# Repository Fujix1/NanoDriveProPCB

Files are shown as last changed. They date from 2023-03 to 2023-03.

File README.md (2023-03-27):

# NanoDriveProPCB
This is a PCB design repository for NanoDrive PRO

<br />この 作品 は <a rel="license" href="http://creativecommons.org/licenses/by-nc-sa/4.0/">クリエイティブ・コモンズ 表示 - 非営利 - 継承 4.0 国際 ライセンス</a>の下に提供されています。

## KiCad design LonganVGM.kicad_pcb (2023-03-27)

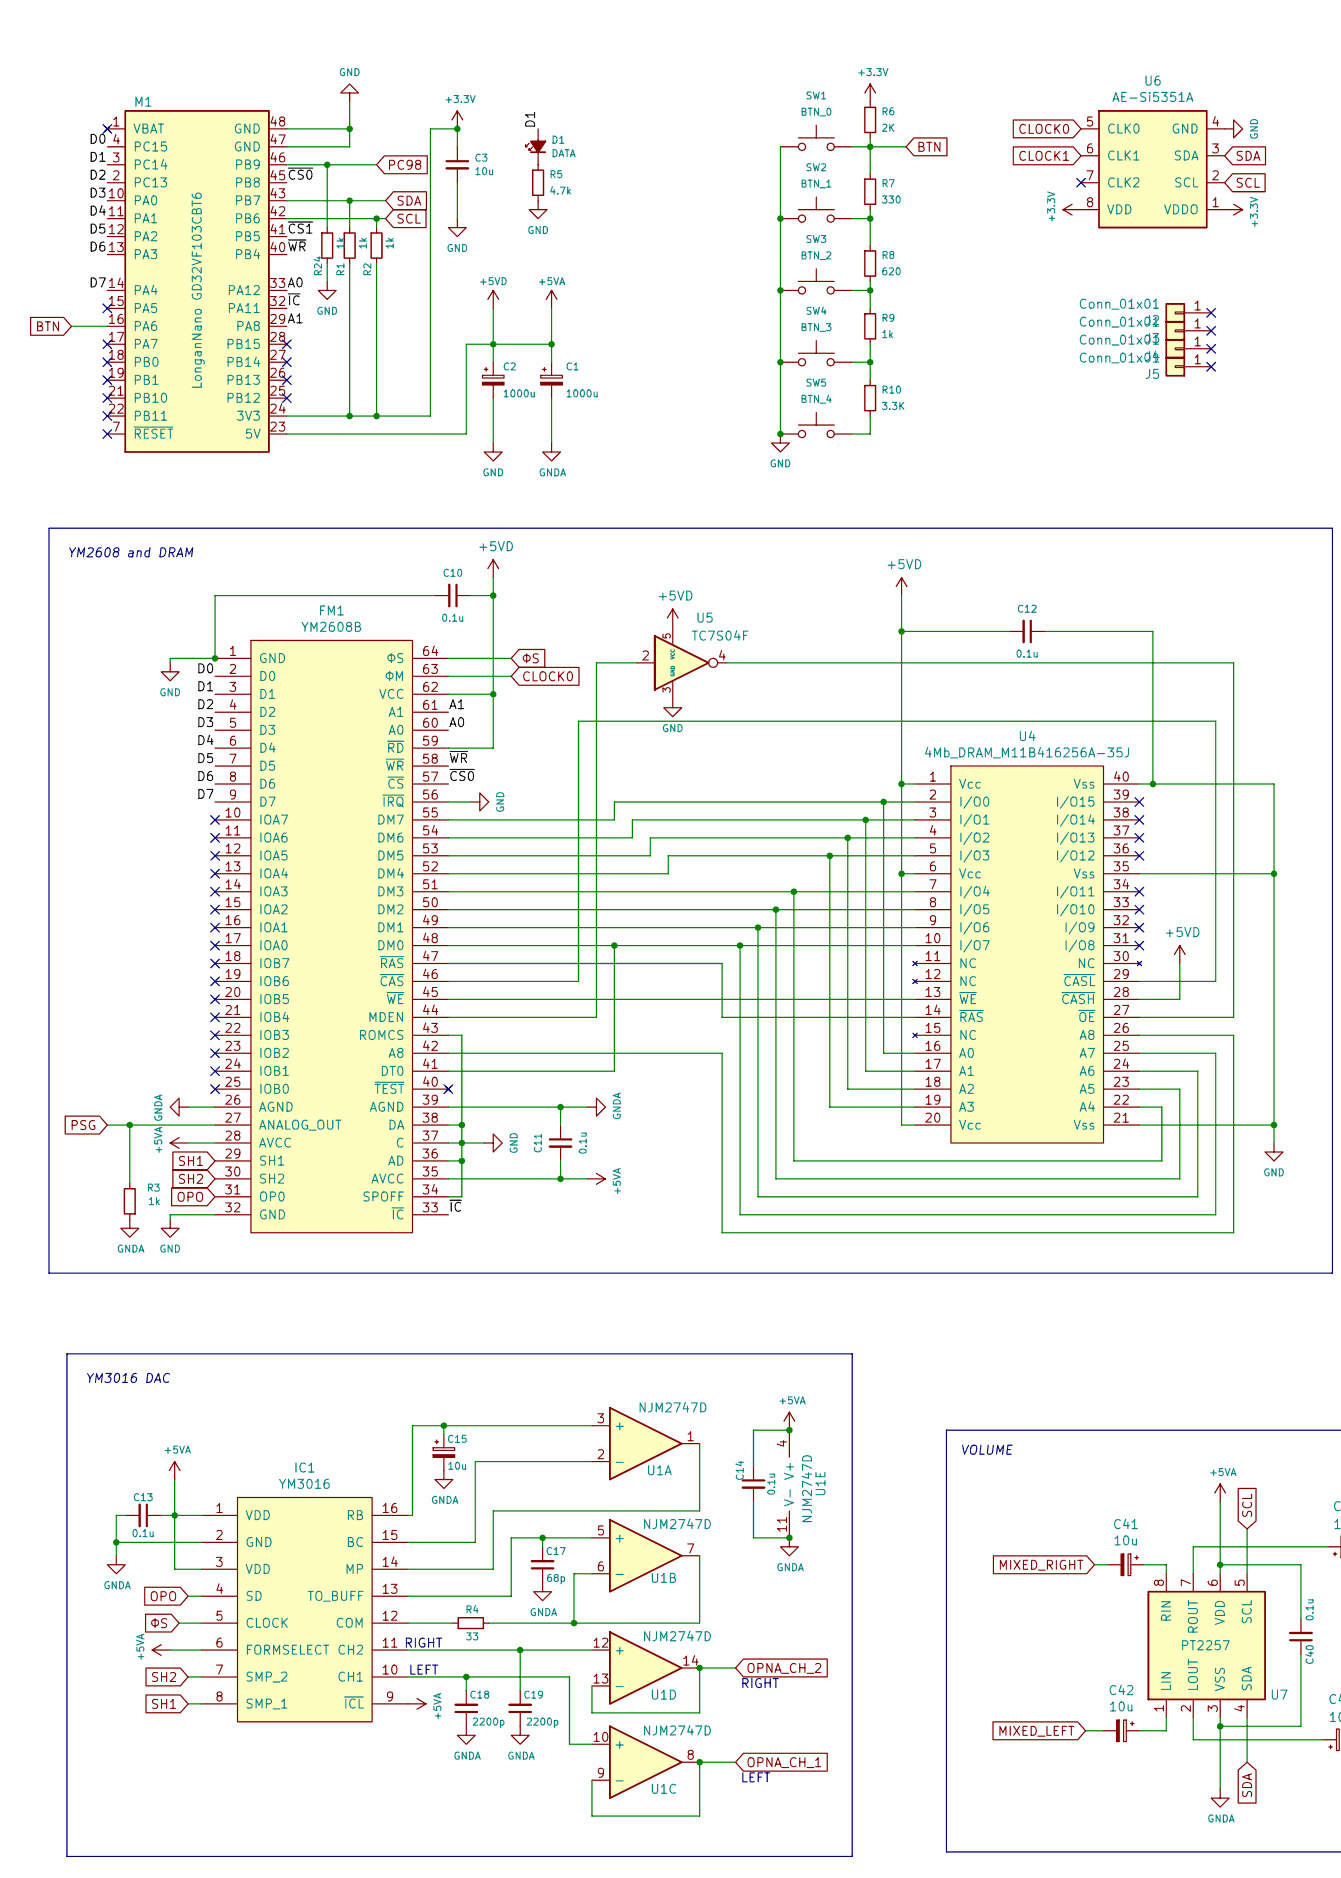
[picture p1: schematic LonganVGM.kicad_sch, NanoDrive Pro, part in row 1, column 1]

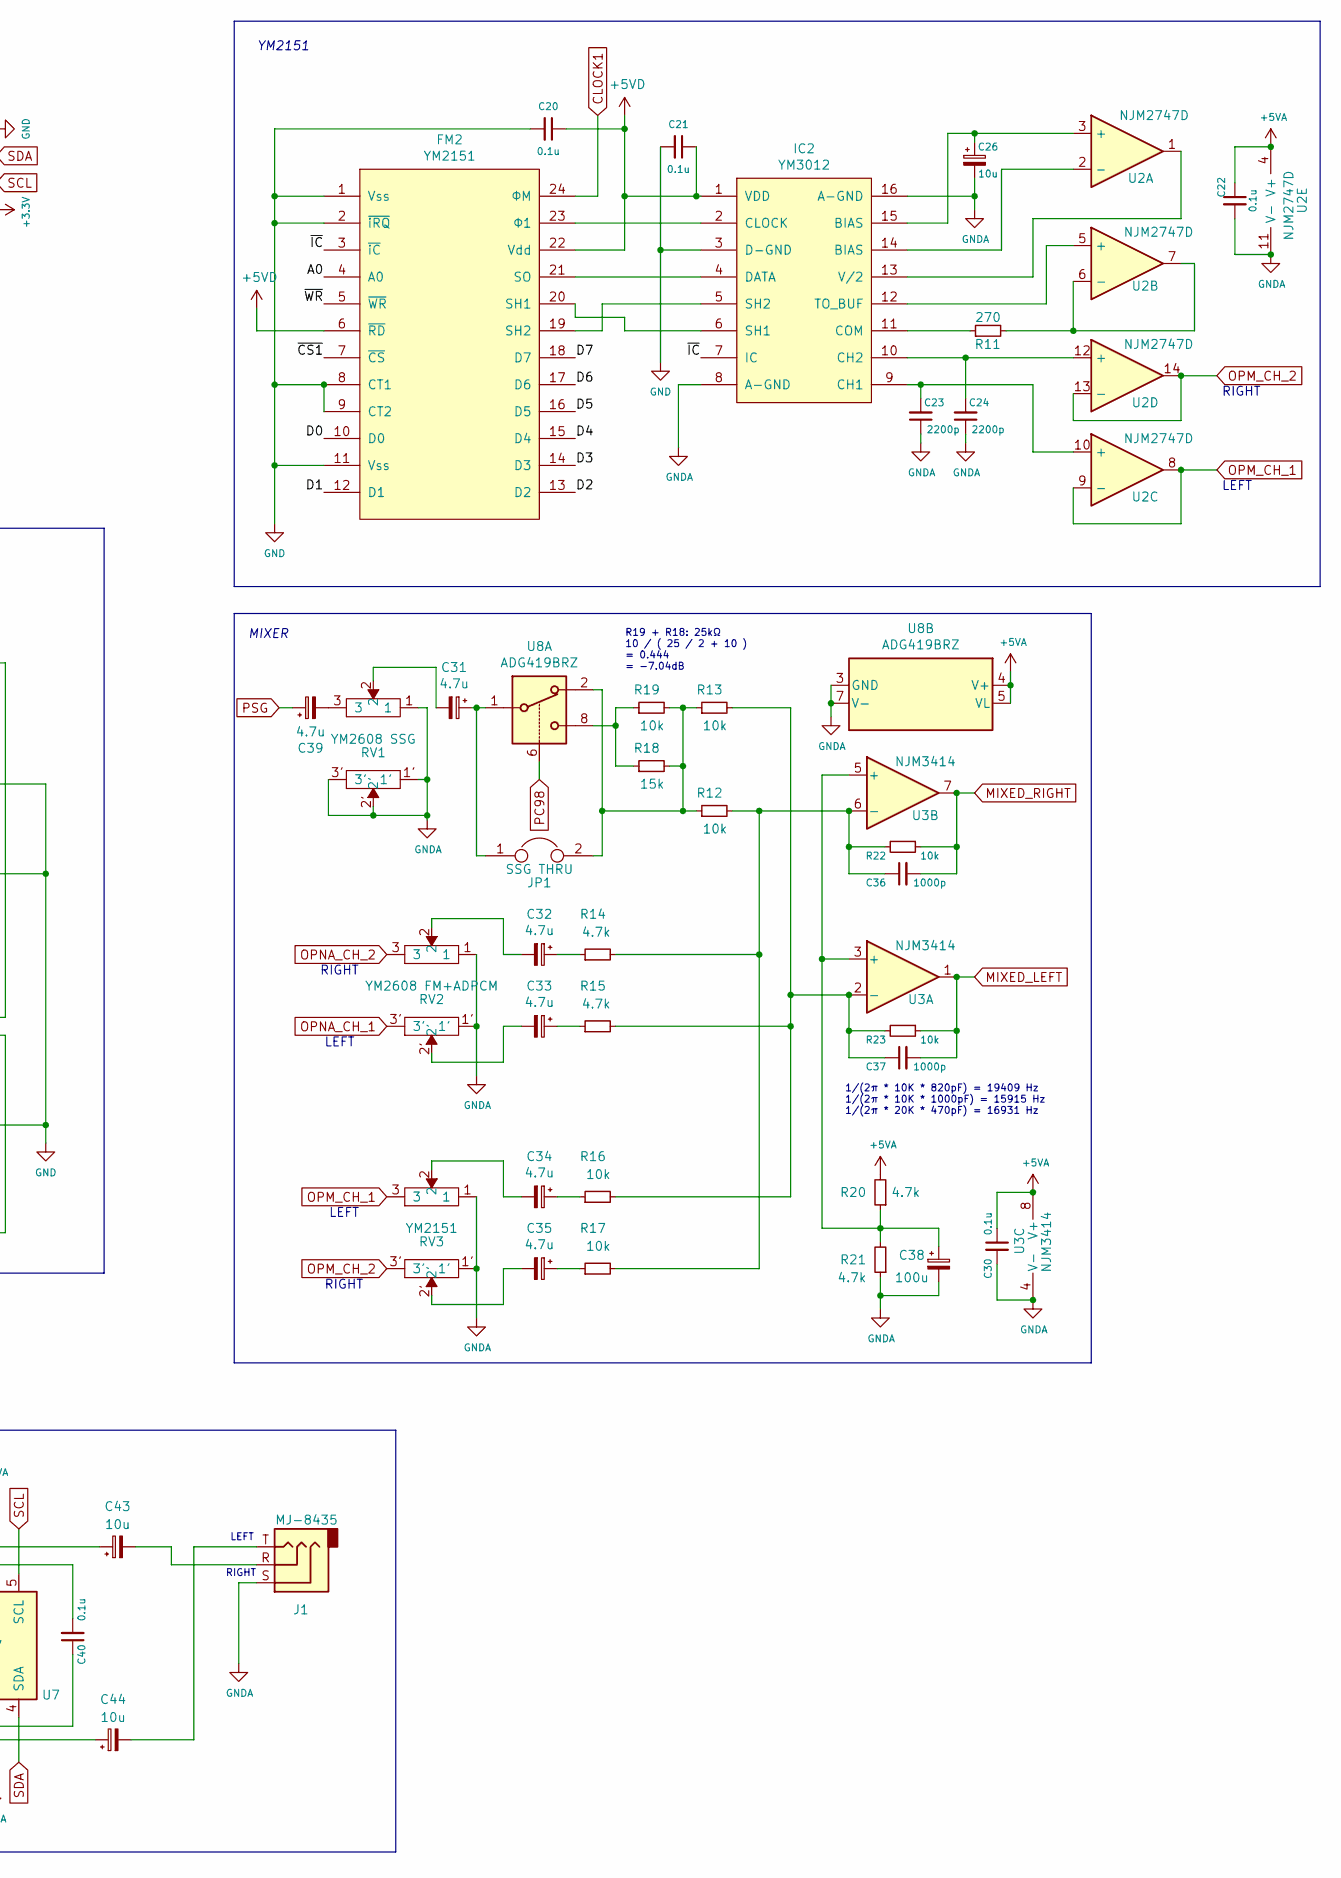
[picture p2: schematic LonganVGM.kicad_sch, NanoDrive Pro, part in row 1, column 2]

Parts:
C1, C2: 1000u; CP_Radial_D8.0mm_P3.50mm
C3, C15, C26, C41, C42, C43, C44: 10u; CP_Radial_D5.0mm_P2.00mm
C10, C11, C12, C13, C14, C20, C21, C22, C30, C40: 0.1u; C_Disc_D4.3mm_W1.9mm_P5.00mm
C17: 68p; C_Disc_D4.3mm_W1.9mm_P5.00mm
C18, C19, C23, C24: 2200p; C_Disc_D4.3mm_W1.9mm_P5.00mm
C31, C32, C33, C34, C35, C39: 4.7u; CP_Radial_D5.0mm_P2.00mm
C36, C37: 1000p; C_Disc_D4.3mm_W1.9mm_P5.00mm
C38: 100u; CP_Radial_D6.3mm_P2.50mm
D1: DATA; LED_Rectangular_W5.0mm_H2.0mm
FM1: YM2608B; SDIP-64
FM2: YM2151; DIP-24_W15.24mm_Socket
IC1: YM3016; DIP-16_W7.62mm_Socket
IC2: YM3012; DIP-16_W7.62mm_Socket
J1: MJ-8435; MJ8435
J2, J3, J4, J5: Conn_01x01; hole
JP1: SSG THRU; PinHeader_1x02_P2.54mm_Vertical
M1: LonganNano GD32VF103CBT6; LonganNano
R1, R2, R3, R9, R24: 1k; R_Axial_DIN0207_L6.3mm_D2.5mm_P7.62mm_Horizontal
R4: 33; R_Axial_DIN0207_L6.3mm_D2.5mm_P7.62mm_Horizontal
R5, R14, R15, R20, R21: 4.7k; R_Axial_DIN0207_L6.3mm_D2.5mm_P7.62mm_Horizontal
R6: 2K; R_Axial_DIN0207_L6.3mm_D2.5mm_P7.62mm_Horizontal
R7: 330; R_Axial_DIN0207_L6.3mm_D2.5mm_P7.62mm_Horizontal
R8: 620; R_Axial_DIN0207_L6.3mm_D2.5mm_P7.62mm_Horizontal
R10: 3.3K; R_Axial_DIN0207_L6.3mm_D2.5mm_P7.62mm_Horizontal
R11: 270; R_Axial_DIN0207_L6.3mm_D2.5mm_P7.62mm_Horizontal
R12, R13, R16, R17, R19, R22, R23: 10k; R_Axial_DIN0207_L6.3mm_D2.5mm_P7.62mm_Horizontal
R18: 15k; R_Axial_DIN0207_L6.3mm_D2.5mm_P7.62mm_Horizontal
RV1: YM2608 SSG; RK12L
RV2: YM2608 FM+ADPCM; RK12L
RV3: YM2151; RK12L
SW1: BTN_0; SW_PUSH_6mm_H4.3mm
SW2: BTN_1; SW_PUSH_6mm_H4.3mm
SW3: BTN_2; SW_PUSH_6mm_H4.3mm
SW4: BTN_3; SW_PUSH_6mm_H4.3mm
SW5: BTN_4; SW_PUSH_6mm_H4.3mm
U1, U2: NJM2747D; DIP-14_W7.62mm_Socket
U3: NJM3414; DIP-8_W7.62mm_Socket
U4: 4Mb_DRAM_M11B416256A-35J; SOP-40
U5: TC7S04F; SOT-23-5_HandSoldering
U6: AE-Si5351A; DIP-8_W7.62mm_Socket
U7: PT2257; DIP-8_W7.62mm_Socket
U8: ADG419BRZ; SO-8_3.9x4.9mm_P1.27mm_handsolder

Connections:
+3V3: C3.1, M1.24 (3V3), R1.2, R2.2, R6.1, U6.1 (VDDO), U6.8 (VDD)
+5VA: C1.1, C2.1, C10.1, C11.2, C12.2, C13.1, C14.1, C20.1, C21.1, C22.1, C30.1, C40.2, FM1.28 (AVCC), FM1.35 (AVCC), FM1.59 (~RD), FM1.62 (VCC), FM2.6 (~RD), FM2.22 (Vdd), IC1.1 (VDD), IC1.3 (VDD), IC1.6 (FORMSELECT), IC1.9 (~ICL), IC2.1 (VDD), M1.23 (5V), R20.2, U1.4 (V+), U2.4 (V+), U3.8 (V+), U4.1 (Vcc), U4.6 (Vcc), U4.20 (Vcc), U4.28 (~CASH), U5.5 (VCC), U7.6 (VDD), U8.4 (V+), U8.5 (VL)
/A0: FM1.60 (A0), FM2.4 (A0), M1.33 (PA12)
/A1: FM1.61 (A1), M1.29 (PA8)
/D0: FM1.2 (D0), FM2.10 (D0), M1.4 (PC15)
/D1: D1.2 (A), FM1.3 (D1), FM2.12 (D1), M1.3 (PC14)
/D2: FM1.4 (D2), FM2.13 (D2), M1.2 (PC13)
/D3: FM1.5 (D3), FM2.14 (D3), M1.10 (PA0)
/D4: FM1.6 (D4), FM2.15 (D4), M1.11 (PA1)
/D5: FM1.7 (D5), FM2.16 (D5), M1.12 (PA2)
/D6: FM1.8 (D6), FM2.17 (D6), M1.13 (PA3)
/D7: FM1.9 (D7), FM2.18 (D7), M1.14 (PA4)
/~CS0: FM1.57 (~CS), M1.45 (PB8)
/~CS1: FM2.7 (~CS), M1.41 (PB5)
/~IC: FM1.33 (~IC), FM2.3 (~iC), IC2.7 (IC), M1.32 (PA11)
/~WR: FM1.58 (~WR), FM2.5 (~WR), M1.40 (PB4)
BTN: M1.16 (PA6), R6.2, R7.1, SW1.2
CLOCK0: FM1.63 (ΦM), U6.5 (CLK0)
CLOCK1: FM2.24 (ΦM), U6.6 (CLK1)
MIXED_LEFT: C37.2, C42.2, R23.1, U3.1
MIXED_RIGHT: C36.2, C41.2, R22.1, U3.7
unnamed: C15.1, IC1.16 (RB), U1.3 (+)
unnamed: C17.2, IC1.13 (TO_BUFF), U1.5 (+)
unnamed: C18.2, IC1.10 (CH1), U1.10 (+)
unnamed: C19.2, IC1.11 (CH2), U1.12 (+)
unnamed: C23.2, IC2.9 (CH1), U2.10 (+)
unnamed: C24.2, IC2.10 (CH2), U2.12 (+)
unnamed: C26.1, IC2.15 (BIAS), U2.3 (+)
unnamed: C31.1, JP1.1, U8.1
unnamed: C31.2, RV1.2
unnamed: C32.1, R14.1
unnamed: C32.2, RV2.2
unnamed: C33.1, R15.1
unnamed: C33.2, RV2.2'
unnamed: C34.1, R16.1
unnamed: C34.2, RV3.2
unnamed: C35.1, R17.1
unnamed: C35.2, RV3.2'
unnamed: C36.1, R12.2, R14.2, R17.2, R22.2, U3.6 (-)
unnamed: C37.1, R13.2, R15.2, R16.2, R23.2, U3.2 (-)
unnamed: C38.1, R20.1, R21.2, U3.3 (+), U3.5 (+)
unnamed: C39.2, RV1.3
unnamed: C41.1, U7.8 (RIN)
unnamed: C42.1, U7.1 (LIN)
unnamed: C43.1, U7.7 (ROUT)
unnamed: C43.2, J1.R
unnamed: C44.1, U7.2 (LOUT)
unnamed: C44.2, J1.T
unnamed: D1.1 (K), R5.1
unnamed: FM1.41 (DT0), FM1.48 (DM0), U4.10 (I/O7), U4.25 (A7)
unnamed: FM1.42 (A8), U4.26 (A8)
unnamed: FM1.44 (MDEN), U5.2
unnamed: FM1.45 (~WE), U4.13 (~WE)
unnamed: FM1.46 (~CAS), U4.29 (~CASL)
unnamed: FM1.47 (~RAS), U4.14 (~RAS)
unnamed: FM1.49 (DM1), U4.9 (I/O6), U4.24 (A6)
unnamed: FM1.50 (DM2), U4.8 (I/O5), U4.23 (A5)
unnamed: FM1.51 (DM3), U4.7 (I/O4), U4.22 (A4)
unnamed: FM1.52 (DM4), U4.5 (I/O3), U4.19 (A3)
unnamed: FM1.53 (DM5), U4.4 (I/O2), U4.18 (A2)
unnamed: FM1.54 (DM6), U4.3 (I/O1), U4.17 (A1)
unnamed: FM1.55 (DM7), U4.2 (I/O0), U4.16 (A0)
unnamed: FM2.19 (SH2), IC2.5 (SH2)
unnamed: FM2.20 (SH1), IC2.6 (SH1)
unnamed: FM2.21 (SO), IC2.4 (DATA)
unnamed: FM2.23 (Φ1), IC2.2 (CLOCK)
unnamed: IC1.12 (COM), R4.1
unnamed: IC1.14 (MP), U1.1
unnamed: IC1.15 (BC), U1.2 (-)
unnamed: IC2.11 (COM), R11.1
unnamed: IC2.12 (TO_BUF), U2.5 (+)
unnamed: IC2.13 (V/2), U2.1
unnamed: IC2.14 (BIAS), U2.2 (-)
unnamed: JP1.2, R12.1, R13.1, R18.2, R19.2, U8.2
unnamed: R4.2, U1.6 (-), U1.7
unnamed: R7.2, R8.1, SW2.2
unnamed: R8.2, R9.1, SW3.2
unnamed: R9.2, R10.1, SW4.2
unnamed: R10.2, SW5.2
unnamed: R11.2, U2.6 (-), U2.7
unnamed: R18.1, R19.1, U8.8
unnamed: U4.27 (~OE), U5.4
OPM_CH_1: RV3.3, U2.8, U2.9 (-)
OPM_CH_2: RV3.3', U2.13 (-), U2.14
OPNA_CH_1: RV2.3', U1.8, U1.9 (-)
OPNA_CH_2: RV2.3, U1.13 (-), U1.14
OPO: FM1.31 (OP0), IC1.4 (SD)
PC98: M1.46 (PB9), R24.1, U8.6
PSG: C39.1, FM1.27 (ANALOG_OUT), R3.2
SCL: M1.42 (PB6), R2.1, U6.2 (SCL), U7.5 (SCL)
SDA: M1.43 (PB7), R1.1, U6.3 (SDA), U7.4 (SDA)
SH1: FM1.29 (SH1), IC1.8 (SMP_1)
SH2: FM1.30 (SH2), IC1.7 (SMP_2)
ΦS: FM1.64 (ΦS), IC1.5 (CLOCK)

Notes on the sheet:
RIGHT
LEFT
R19 + R18: 25kΩ 10 / ( 25 / 2 + 10 ) = 0.444 = -7.04dB
1/(2π * 10K * 820pF) = 19409 Hz 1/(2π * 10K * 1000pF) = 15915 Hz 1/(2π * 20K * 470pF) = 16931 Hz
YM2608 and DRAM
RIGHT
YM2151
YM3016 DAC
MIXER
VOLUME

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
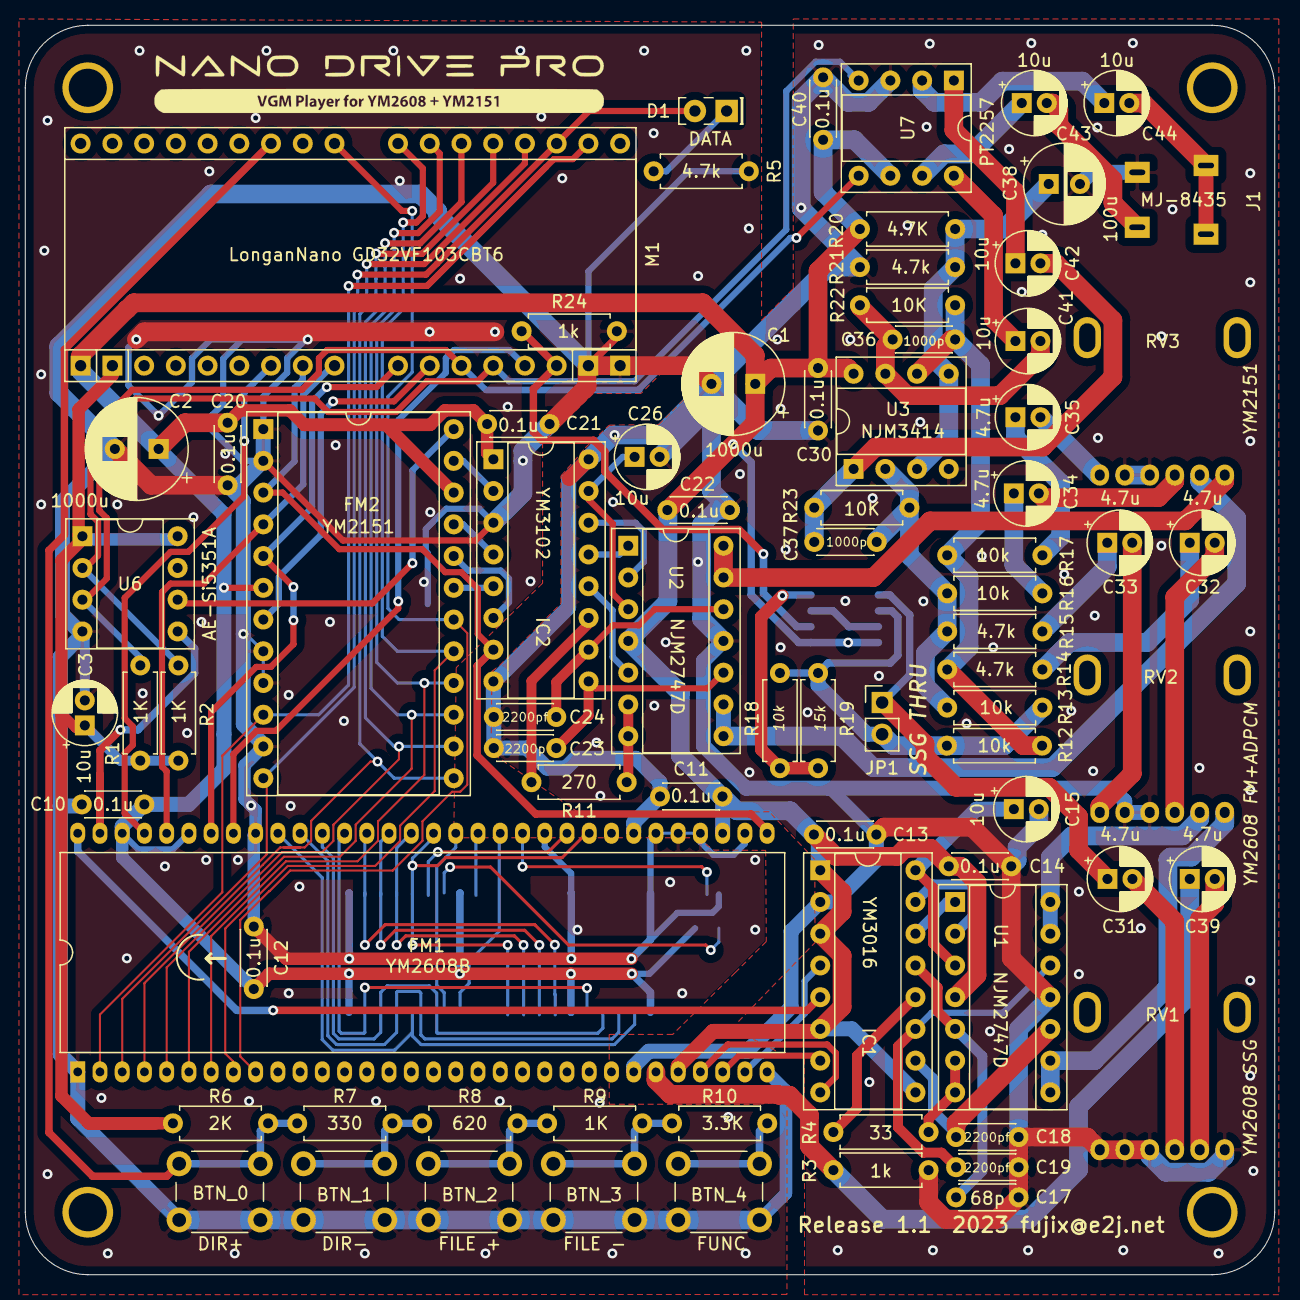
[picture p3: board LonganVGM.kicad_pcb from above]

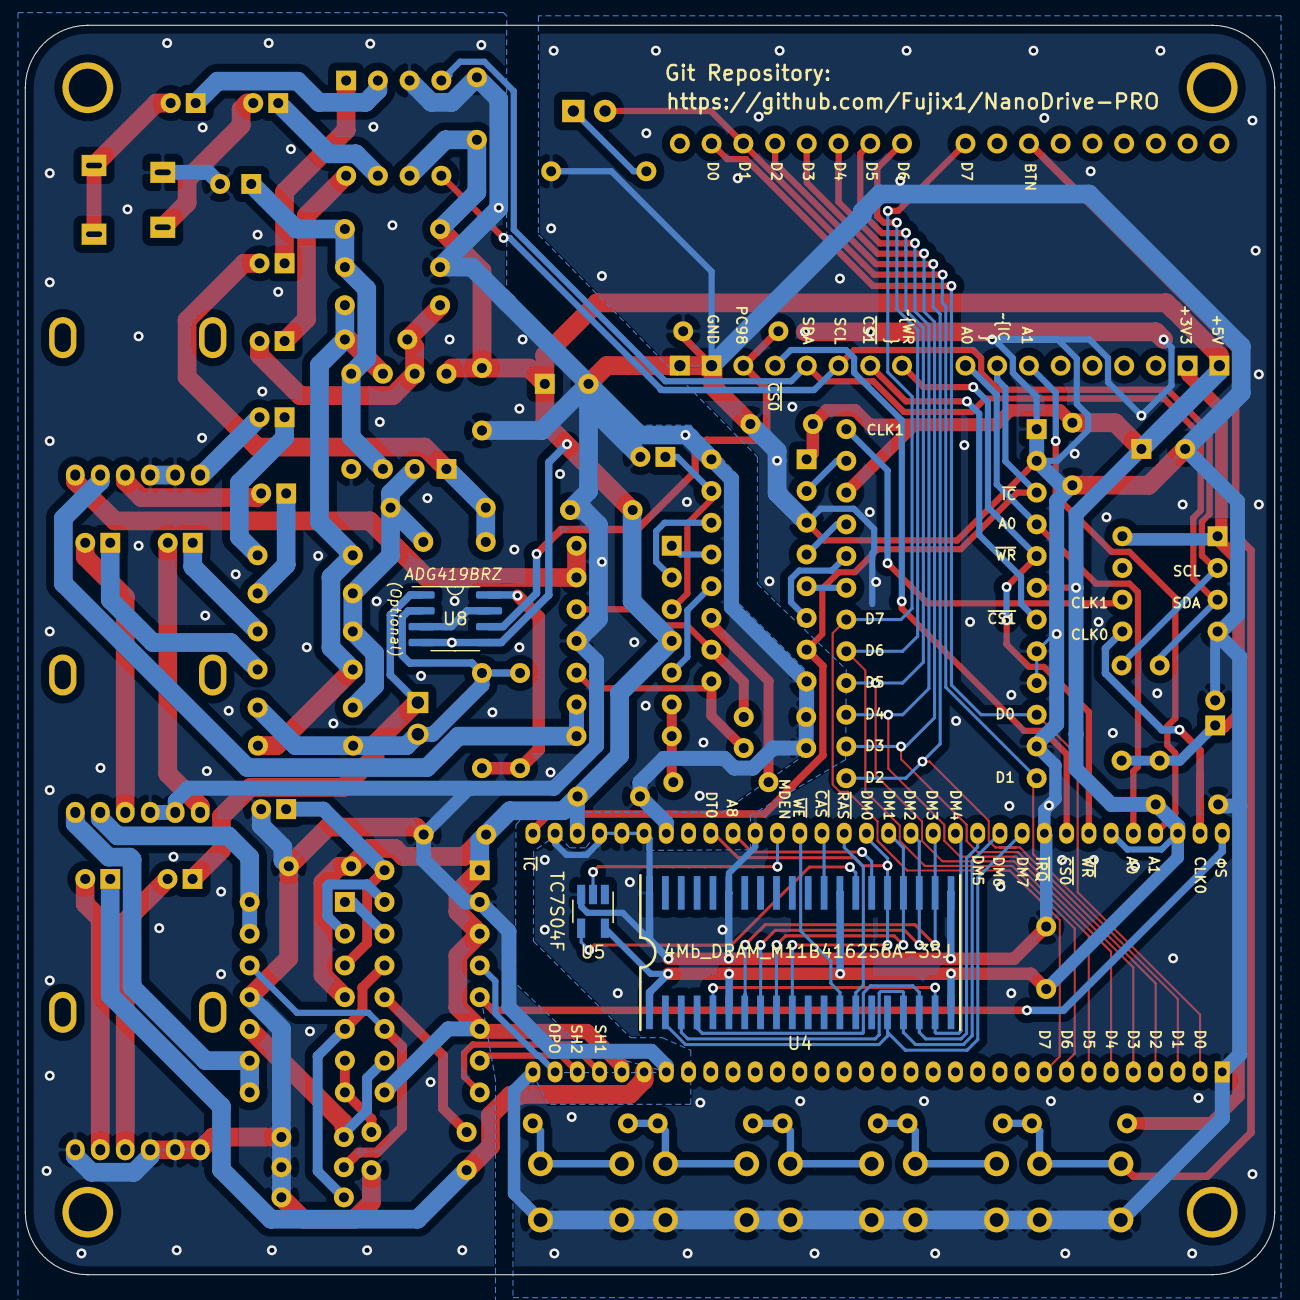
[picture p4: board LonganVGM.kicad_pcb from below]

Board: 2 copper layers, 100.0 x 100.0 mm, 85 parts (3 on the bottom side), 95 nets.

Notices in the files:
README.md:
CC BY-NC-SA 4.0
